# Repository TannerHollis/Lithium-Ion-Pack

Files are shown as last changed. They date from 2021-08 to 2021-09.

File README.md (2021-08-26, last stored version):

# Lithium Ion Pack
This project an open-source Lithium Ion Battery Pack charger and management system. Over the years, I have used many Lithium Ion cells and struggled over the exact workings of **smart-charging** and **cell balancing**. These terms are thrown around as to create a magic around the lithium ion battery charging process. The schematic, although very intricate can be broken down into **three** major components:
 **1.**  The battery charging circuit.
 **2.**  The battery balancing and protection circuit.
 **3.**  The voltage and current measurement circuit.

## The Battery Charging Circuit

I have used many battery charging Integrated Circuits in the past and have never been able to fully conceive what is going on behind the curtains of the larger devices which charge multiple cells. In fact, the basics *seem* very simple. Constant current until you achieve a specific voltage. Constant voltage until you stop after a certain time, giving the batteries a moment to "top-off". 

This battery pack is able to charge via a USB-C type port, which is a standard USB2.0 port used for Virtual Communications over USB. Since it's a standard USB2.0 connector inside of USB-C, only 5V is input to the device. The included Boost converter then steps-up the voltage through the [PAM2423](https://www.diodes.com/assets/Datasheets/PAM2421_22_23.pdf) DC-DC step-up voltage regulator. While this step-up regulator is capable of producing output voltages of up to 24V, the circuit is controlled by the feedback resistor network.

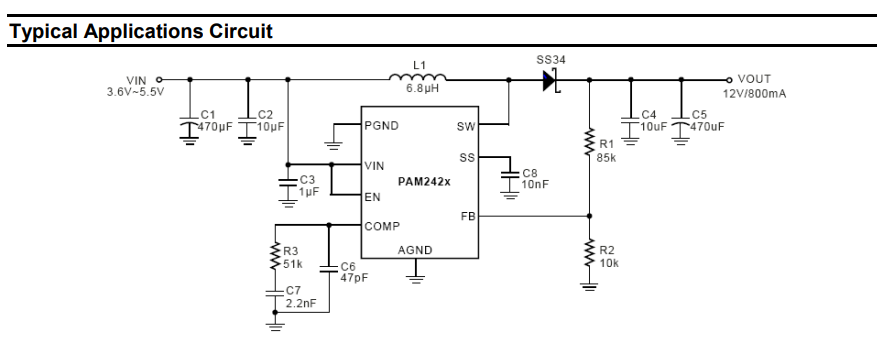
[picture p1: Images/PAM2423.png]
PAM2423 Typical Application Diagram


Since the resistor network can be controlled by a resistor network, I propose controlling the output voltage through the use of a digital potentiometer, [MCP4351](http://ww1.microchip.com/downloads/en/DeviceDoc/22242A.pdf). This device is essentially a digitally controlled resistor divider through SPI communications. 

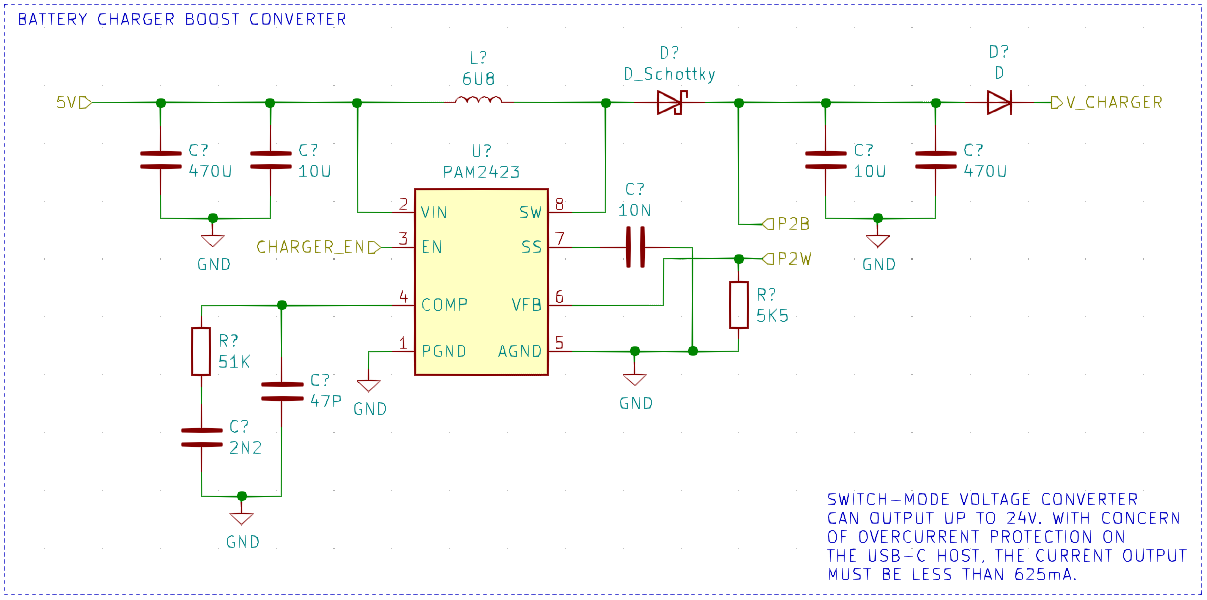
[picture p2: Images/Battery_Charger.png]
Battery Charger Circuit


When calculating the possible output voltages using only the resistor divider network, the following equation dictates the output voltage *(datasheet, pg. 6)*:

$$\begin{equation}V_{out} = (\frac{R_1}{R_2} + 1) * 1.262\end{equation}$$

The MCP4351 has a total different number of 257 different positions or "taps" that the potentiometer can place the "wiper". The resistor divider network's is calculated as follows *(datasheet, pg. 43)*:

$$\begin{equation}\begin{split}
R_{aw} &= \frac{100*10^3*n}{256}+75\\
R_{wb} &= \frac{100*10^3*(257-n)}{256}+75\\
\\
R_{aw}(0) &= 75\Omega\\
R_{wb}(0) &= 10.465k\Omega\\
\\
R_{aw}(257) &= 10.465k\Omega\\
R_{wb}(257) &= 75\Omega\\
\end{split}\end{equation}$$

Therefore, the the output voltage of the converter can be expressed as an quadratic with an asymptote, where $R_1 = R_{aw}$ and $R_2 = R_{wb}$:

$$\begin{equation}
\begin{split}
V_{out}(&n) = (100*10^3*\frac{n}{257 - n} + 1)*1.262V\\
V_{out}(&0) = 1.262V\\
V_{out}(&257) = \infin\\
\end{split}
\end{equation}
$$

Obviously, this equation poses a serious issue, infinity is not possible when the maximum allowed output voltage of the switching regulator is 24V. In order to combat this issue, only half of the wiper will be used. Since the wiper position at instruction *000h* for $R_{wb}$ is 0 Ohms, only the bottom half of the resistor divider in the MCP4351 and a static 5.5kOhm resistor will be used as follows:

$$\begin{equation}
\begin{split}
V_{out}(&n) = (\frac{100*10^3}{256}*\frac{n}{5.5*10^3} + 1)*1.262V\\
V_{out}(&0) = 1.262V\\
V_{out}(&257) = 24.30V\\
\end{split}
\end{equation}
$$

Creating the resistor divider this way with a fixed resistor on the bottom half of the feedback network creates a linear equation, which allows for more granularity. In fact, the minimum granularity between each LSb sent to the digital potentiometer is:

$$\begin{equation}V_{out}(1) - V_{out}(0) = 1.352V - 1.262V = 89.63mV\end{equation}$$

The resistor feeding the battery cells is 5 Ohms, which dictates current steps into the battery pack per change in voltage:

$$\begin{equation}I_{charge} = \frac{89.63V}{5\Omega} = 17.93 mA\end{equation}$$

This makes the current granularity small enough to manage on a larger scale and easier to manage from the current regulation PID controller. One thing to note in this setup is that due to the maximum wattage of the resistor of 5W, the device is only capable of sourcing up to 1 Amp into the battery pack. Which results in the following number of maximum voltage steps to the voltage regulator:
$$\begin{equation}n_{volts} = \frac{I_{chg}*R_{chg}}{89.63mV}=\frac{1A*5\Omega}{89.63mV}=55.8 \text{ steps truncated}=55\text{ steps}\end{equation}$$

## The Battery Balancing and Protection Circuit
While most IC's use a standard common drain N-Channel MOSFET pair to protect the battery pack, I am going with an easier approach to battery protection, with a P-Channel MOSFET. The gate is held high with a pull-up resistor until the device monitors an overcurrent/over-discharge condition. Otherwise the circuit features a soft-start turn-on with the help of a slow RC circuit with a fast discharge diode. Similar to that of a unstable 555 timer circuit.

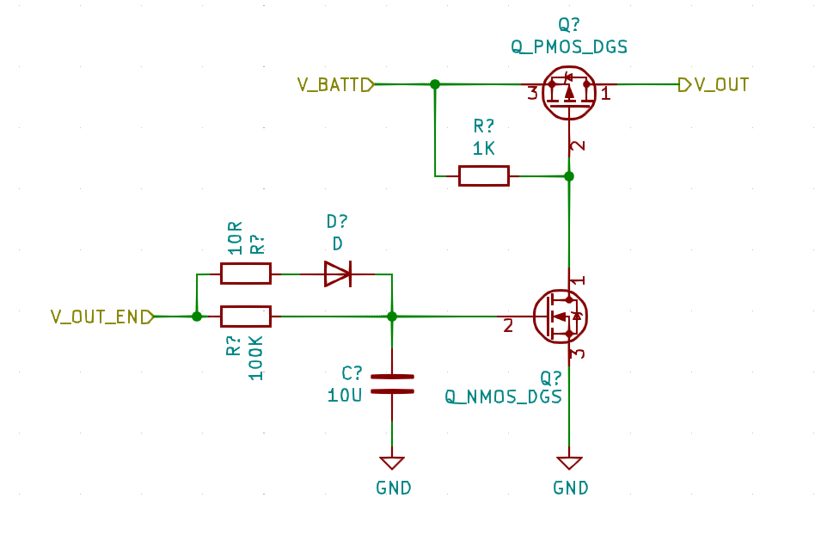
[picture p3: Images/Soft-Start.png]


When the signal to the N-Channel MOSFET is sent, it slowly charges the gate capacitor through the 100 kiloOhm capacitor. The RC time constant is 1 second. In the event of a fault - overcurrent, overdischarge or undervoltage - the capacitor quickly discharges through the 10 Ohm resistor through the diode. Once the forward voltage of diode is reached, the capacitor continues to discharge through the 100K resistor until completely discharged. This feature allows a rapid turn-off circuit and a slow turn-on circuit in the case of a close-onto-fault scenario.

TODO:

 - [ ] Continue editing this document
 - [ ] Assemble and build prototype
 - [ ] Revise design after basic testing
 - [ ] Verify programming and charging operation
 - [ ] Cycle battery discharge/charging

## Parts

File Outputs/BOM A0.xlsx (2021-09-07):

Bill of Materials
Lithium Ion Battery Pack |  |  |  | Started: September 3rd, 2021 Finished:
 |  |  |  | Total | 124 |  | $36.59045
Component | Reference(s) | Value | JLCPCB Code | Digikey Code | Quantity | Cost | Subtotal
Inductor | L2 | 6U8 |  | SRN5020TA-6R8MCT-ND | 1 | $0.57000 | $0.57000
Single-cell battery | BT1, BT2, BT3, BT4 | Battery_Cell |  |  | 4 |  | $0.00000
Unpolarized capacitor | C1, C2 | 30P |  | 490-1414-1-ND | 2 | $0.12000 | $0.24000
Unpolarized capacitor | C3, C9, C15, C16, C17, C18, C19, C20 | 100N |  | 490-4779-1-ND | 8 | $0.11000 | $0.88000
Unpolarized capacitor | C4, C11 | 470U |  | PCE4009CT-ND | 2 | $0.84000 | $1.68000
Unpolarized capacitor | C5 | 2N2 |  | 490-4931-1-ND | 1 | $0.10000 | $0.10000
Unpolarized capacitor | C6, C10 | 10U |  | 490-9965-1-ND | 2 | $0.34000 | $0.68000
Unpolarized capacitor | C7 | 47P |  | 490-1343-1-ND | 1 | $0.11000 | $0.11000
Unpolarized capacitor | C8 | 10N |  | 490-4781-1-ND | 1 | $0.10000 | $0.10000
Unpolarized capacitor | C12 | 33P |  | 490-1339-1-ND | 1 | $0.11000 | $0.11000
Unpolarized capacitor | C13, C14 | 22U |  | 490-5309-1-ND | 2 | $0.52000 | $1.04000
Unpolarized capacitor | C21 | 1U |  | 490-5860-1-ND | 1 | $0.33000 | $0.33000
Resistor | CSR1 | 5R |  | CB5JB5R00-ND | 1 | $0.50000 | $0.50000
Resistor | CSR2, CSR3, CSR4, CSR5 | 8L |  | 2019-TLRH3APTTE8L00FCT-ND | 4 | $1.58000 | $6.32000
Zener diode | D1 | 5V |  | 1727-8310-1-ND | 1 | $0.17000 | $0.17000
Schottky diode | D2, D3 | D_Schottky |  | 641-SS34B-HFCT-ND | 2 | $0.43000 | $0.86000
TVS Diode Array, 5.5V Standoff, 2 Channels, SOT-23 package | D4 | SP0502BAHT |  | F2714CT-ND | 1 | $0.71000 | $0.71000
Diode | D5 | D |  | SS16FL-TPMSCT-ND | 1 | $0.36000 | $0.36000
LED | D6, D7, D8 | LED |  | 732-5031-1-ND | 3 | $0.20000 | $0.60000
Ferrite bead | FB1 | Ferrite_Bead |  | MH3261-601YCT-ND | 1 | $0.10000 | $0.10000
USB-C Connector | J1 | USB4110-GF-A_REVB |  | 2073-USB4110-GF-A-1-ND | 1 | $1.41000 | $1.41000
Board Tabs | J2 | BATTERY_CONNECTIONS |  |  | 1 |  | $0.00000
Inductor | L1 | 6U8 |  | SRN5020TA-6R8MCT-ND | 1 | $0.57000 | $0.57000
N-MOSFET transistor, drain/gate/source | Q1, Q11 | 2N7002T-TP |  | 353-2N7002T-TPCT-ND | 2 | $0.40000 | $0.80000
P-MOSFET transistor, drain/gate/source | Q2, Q7, Q8, Q9, Q10 | MCH3375 |  | MCH3375-TL-WOSCT-ND | 5 | $0.36000 | $1.80000
P-MOSFET transistor, drain/gate/source | Q12 | IPB80P04P4L |  | 448-IPB80P04P4L06ATMA2CT-ND | 1 | $2.07000 | $2.07000
NPN transistor, base/collector/emitter | Q3, Q4, Q5, Q6 | MMST4401 |  | MMST4401TPMSCT-ND | 4 | $0.28000 | $1.12000
Resistor | R1, R41, R42, R43, R44, R56 | 1K5 |  | 541-4209-1-ND | 6 | $0.10000 | $0.60000
Resistor | R2, R5, R45, R46, R47, R48 | 100K |  | 541-4208-1-ND | 6 | $0.10000 | $0.60000
Resistor | R3 | 51K |  | 541-51KECT-ND | 1 | $0.10000 | $0.10000
Resistor | R4, R9, R14, R15, R16, R17, R18, R21 | 10K |  | 541-3983-1-ND | 8 | $0.10000 | $0.80000
Resistor | R6 | 5K49 |  | 541-5.49KFCT-ND | 1 | $0.10000 | $0.10000
Resistor | R7 | 25K5 |  | P25.5KFCT-ND | 1 | $0.10000 | $0.10000
Resistor | R8 | 115K |  | RMCF1206FT115KCT-ND | 1 | $0.10000 | $0.10000
Resistor | R10, R11, R25, R26, R27, R28, R29, R30, R31, R32, R55 | 1K |  | 541-3980-1-ND | 11 | $0.10000 | $1.10000
Resistor | R12 | 13K7 |  | 541-13.7KFCT-ND | 1 | $0.10000 | $0.10000
Resistor | R13 | 6K |  | RNCP1206FTD6K04CT-ND | 1 | $0.10000 | $0.10000
Resistor | R19, R20 | 3K3 |  | 541-4191-1-ND | 2 | $0.10000 | $0.20000
Resistor | R22, R24 | 5K1 20% |  | 541-5.10KFCT-ND | 2 | $0.10000 | $0.20000
Resistor | R23 | 1M |  | 541-4174-1-ND | 1 | $0.10000 | $0.10000
Resistor | R33, R34, R35, R36, R37, R38, R39, R40 | 732R |  | 541-732FCT-ND | 8 | $0.10000 | $0.80000
Resistor | R49, R50, R51, R52 | 160R |  | RMCF1206JT160RCT-ND | 4 | $0.10000 | $0.40000
Resistor | R53 | 10R |  | 541-4202-1-ND | 1 | $0.10000 | $0.10000
Resistor | R54 | 499K |  | RMCF1206FT499KCT-ND | 1 | $0.10000 | $0.10000
Resistor | R57, R58, R59 | 2K |  | RNCP1206FTD2K00CT-ND | 3 | $0.10000 | $0.30000
Tactile Switch | SW1 | KMR233GLFG |  | 401-1430-1-ND | 1 | $0.32045 | $0.32045
ARM Cortex-M3 MCU, 64KB flash, 32KB RAM, 32MHz, 1.65-3.6V, 37 GPIO, UFQFPN-48 | U1 | STM32L151C8UxA |  |  | 1 |  | $0.00000
Quad SPI Digital Potentiometer with Volatile Memory | U2 | MCP4351-104E |  | MCP4351-104E/ML-ND | 1 | $1.64000 | $1.64000
Step-Up Boost Controller | U3 | PAM2423 |  | PAM2423AECADJRDICT-ND | 1 | $1.12000 | $1.12000
3.5A, 18V, 500kHz ACOTTM SynchronousStep-Down Converter | U4 | RT7295A |  | 1028-1459-1-ND | 1 | $1.28000 | $1.28000
300mA low dropout linear regulator, low quiescent current very, low noise, shutdown pin, 3.3V fixed positive output, SOT-23-5/SOT-353-5/SC-70-5 | U5 | LDK130-33 |  | 497-13705-1-ND | 1 | $0.75000 | $0.75000
Low-Power, Quad-Operational Amplifiers, DIP-14/SOIC-14/SSOP-14 | U6, U7, U8 | LM2902 |  | 497-10426-1-ND | 3 | $0.64000 | $1.92000
Two pin crystal | Y1 | 8 MHz |  | 535-14365-1-ND | 1 | $0.43000 | $0.43000

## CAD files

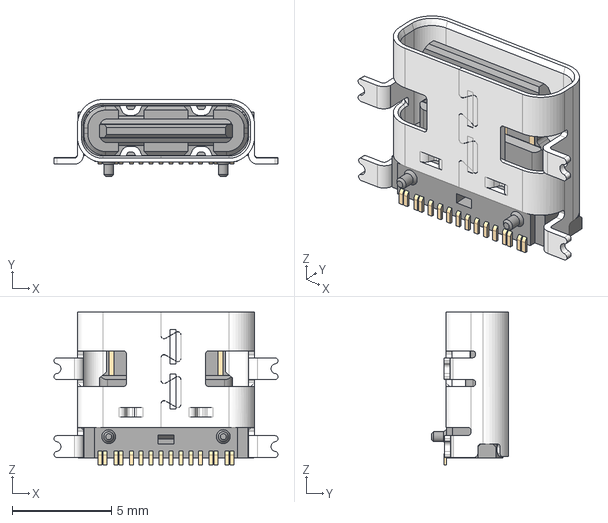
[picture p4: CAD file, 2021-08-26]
Parts/GCT_USB4110GFA/USB4110-GF-A.stp
11.3 x 3.89 x 7.70 mm

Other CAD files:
Parts/USB4110-GF-A_REVB/USB4110-GF-A_REVB.step

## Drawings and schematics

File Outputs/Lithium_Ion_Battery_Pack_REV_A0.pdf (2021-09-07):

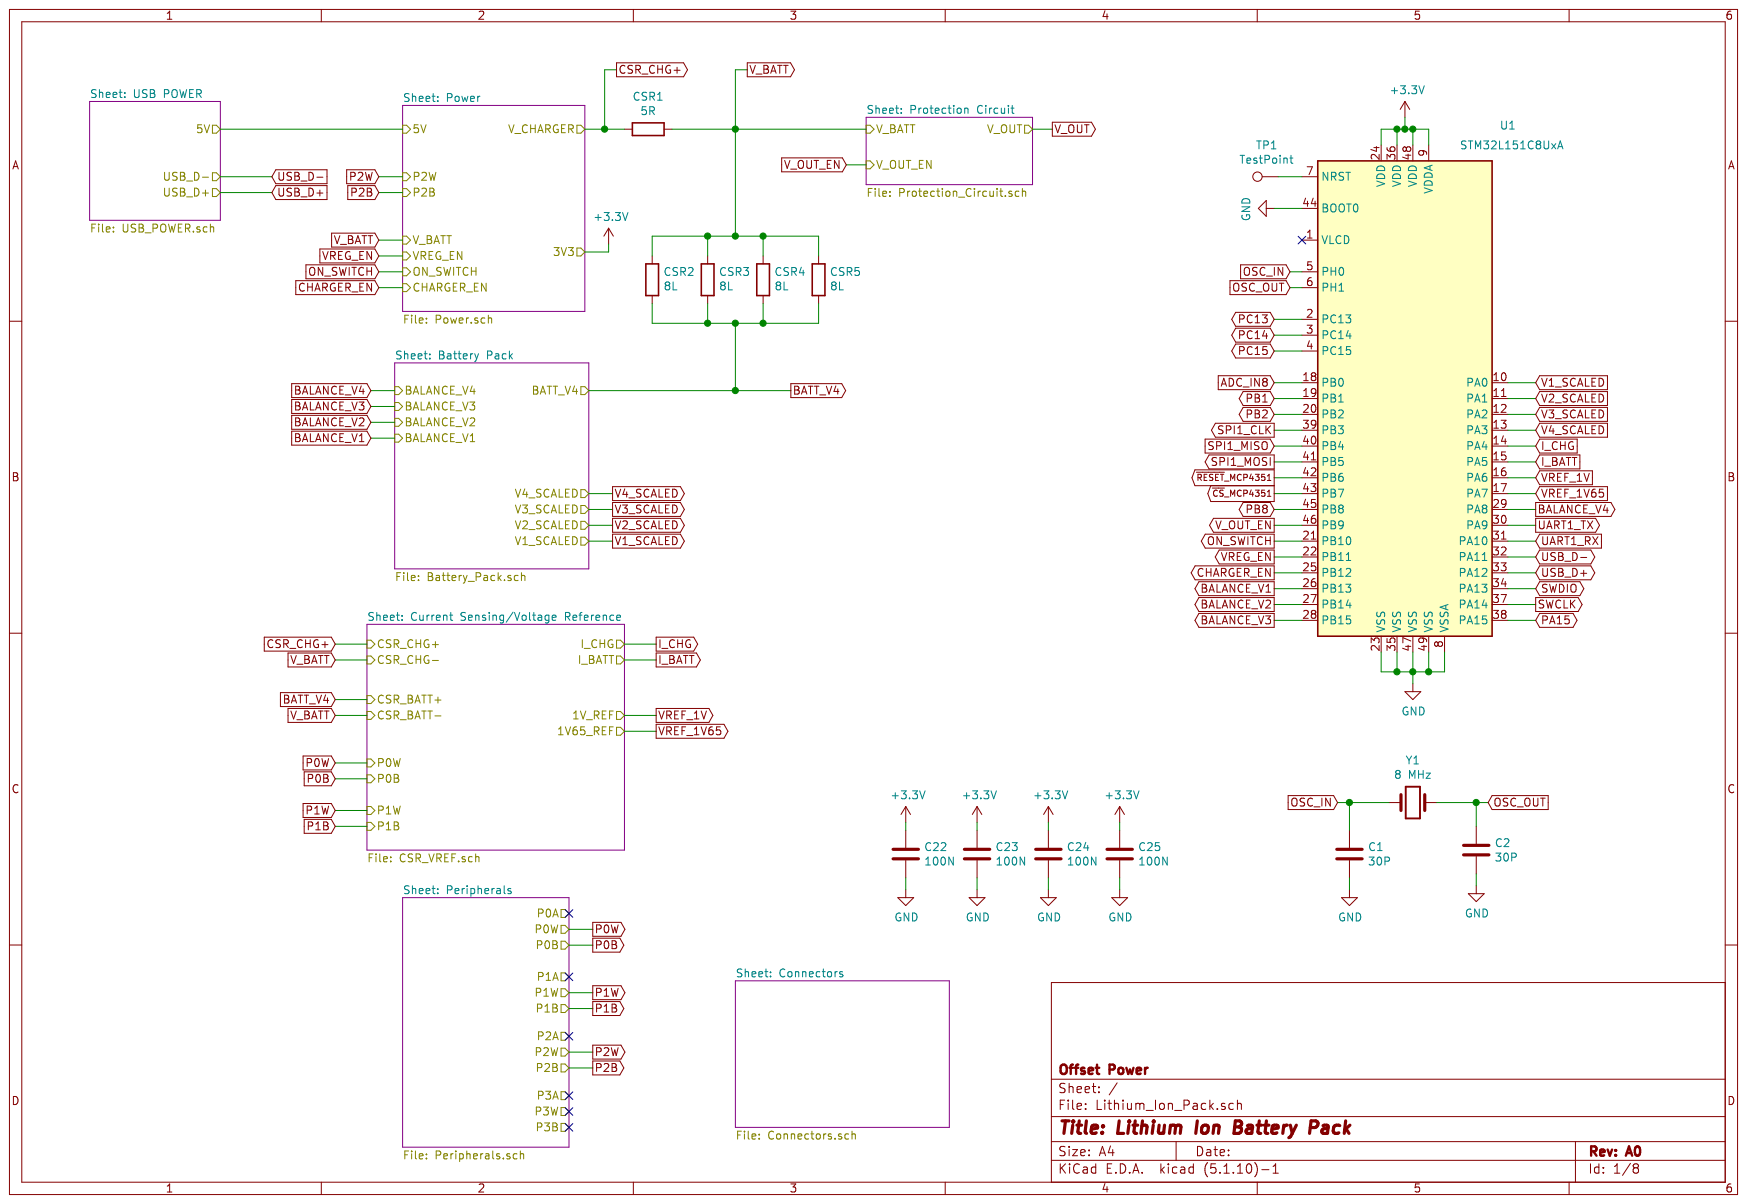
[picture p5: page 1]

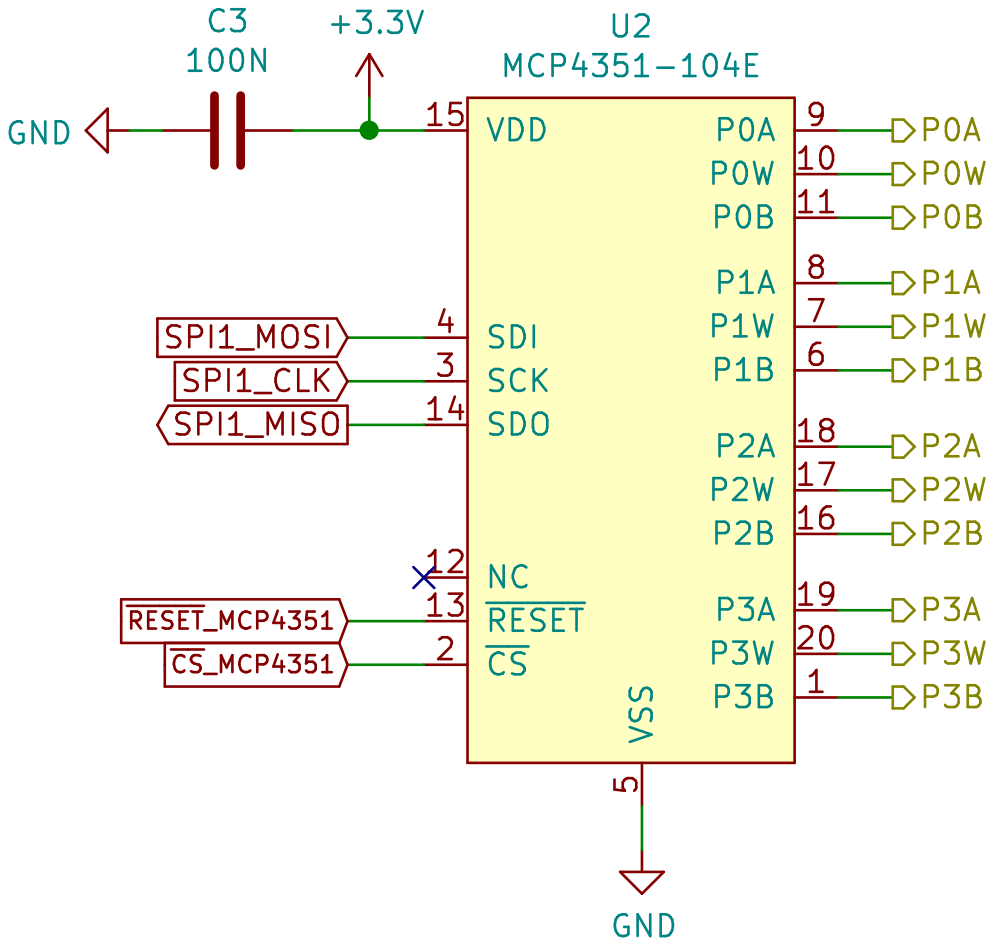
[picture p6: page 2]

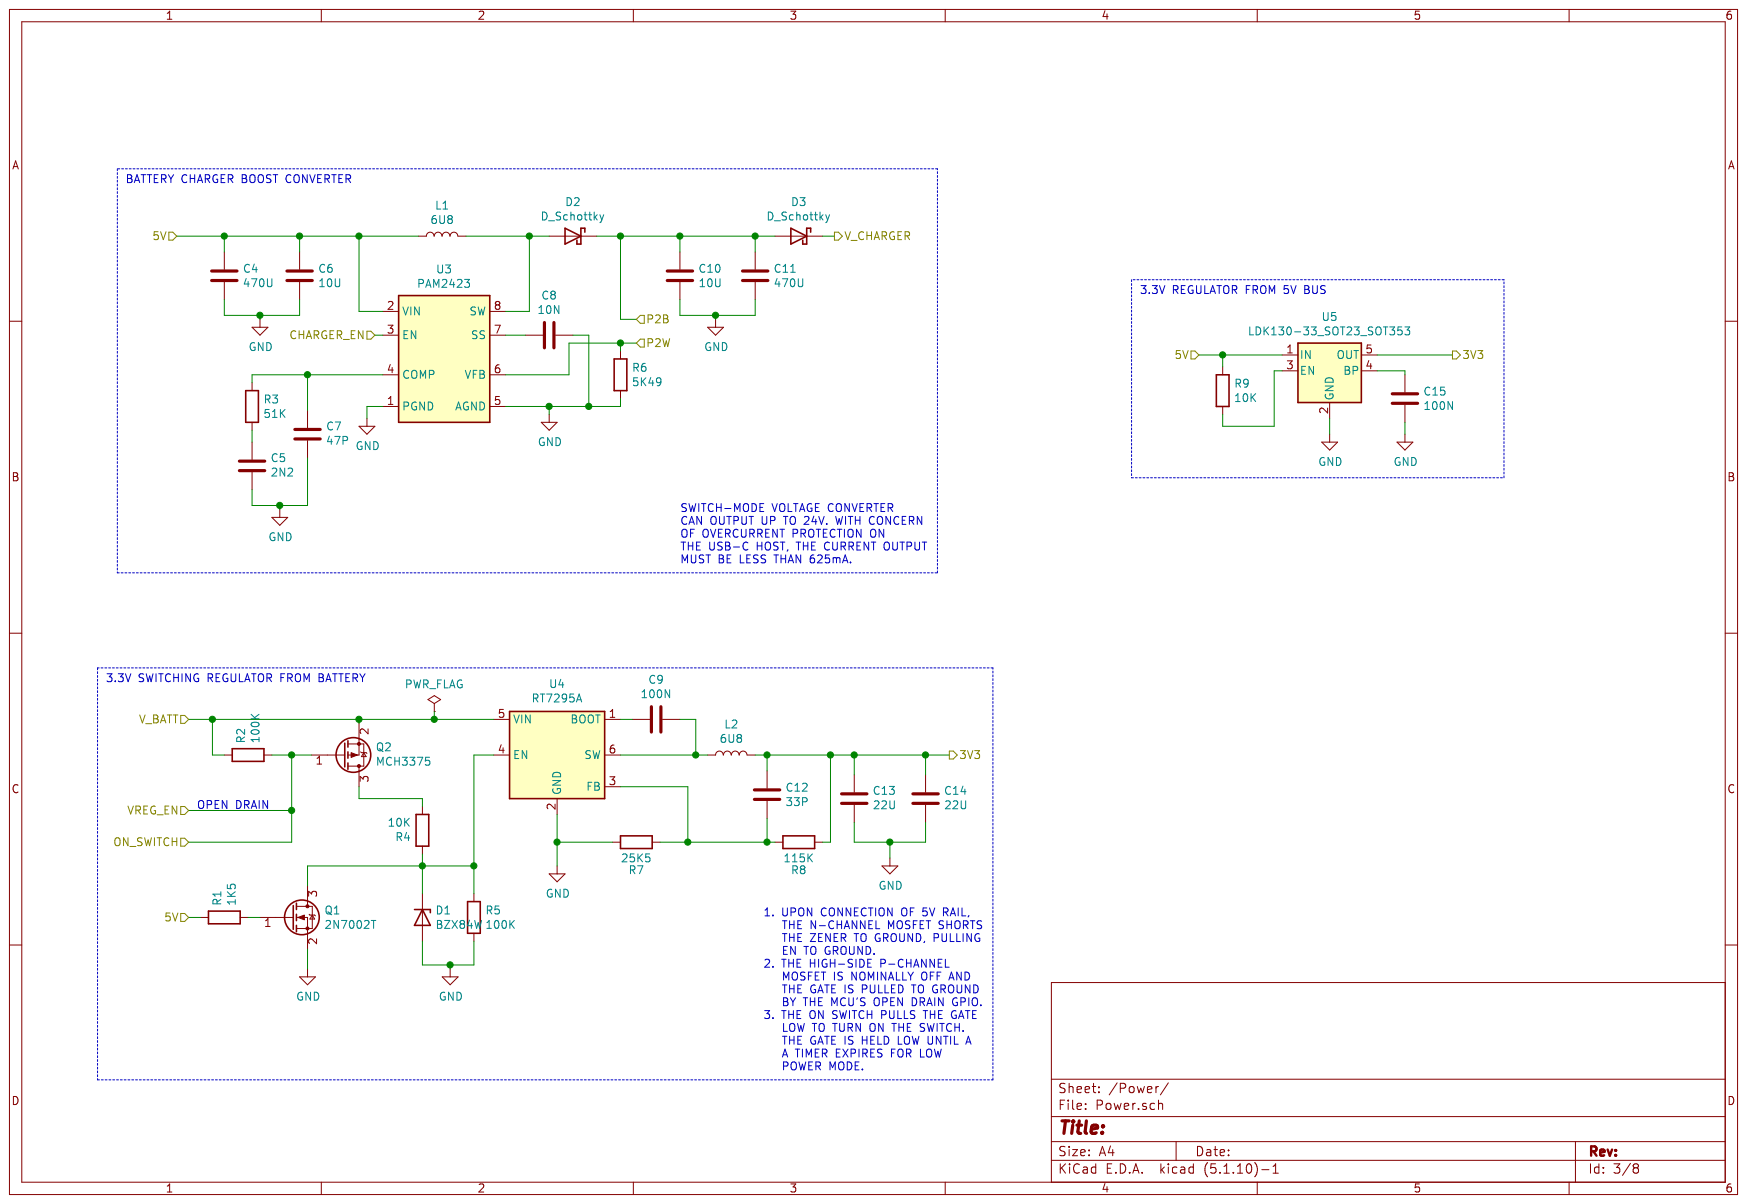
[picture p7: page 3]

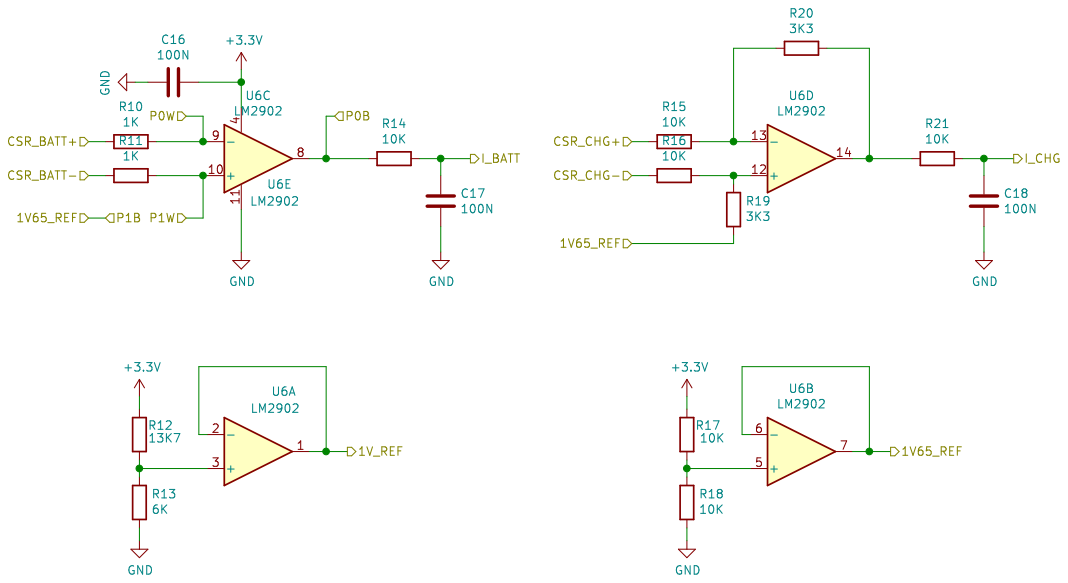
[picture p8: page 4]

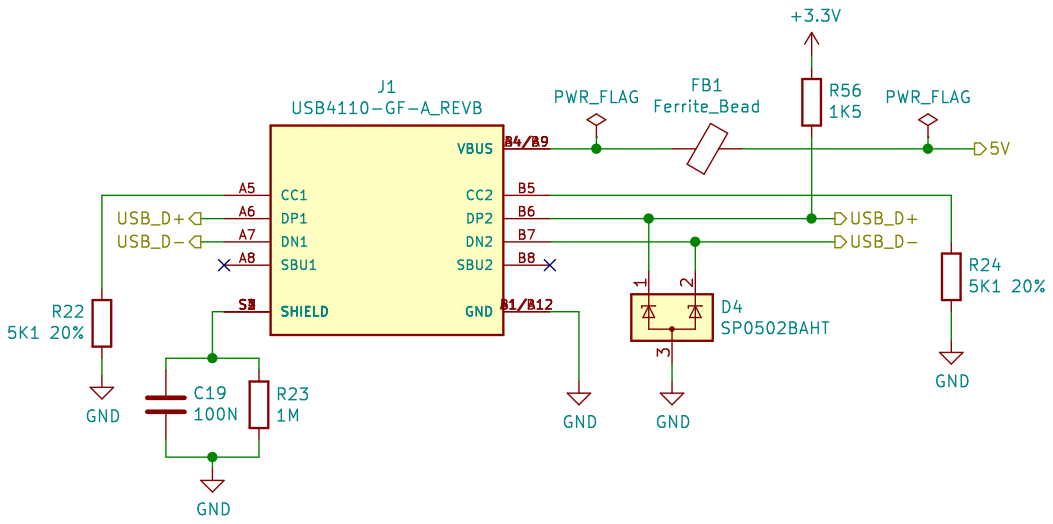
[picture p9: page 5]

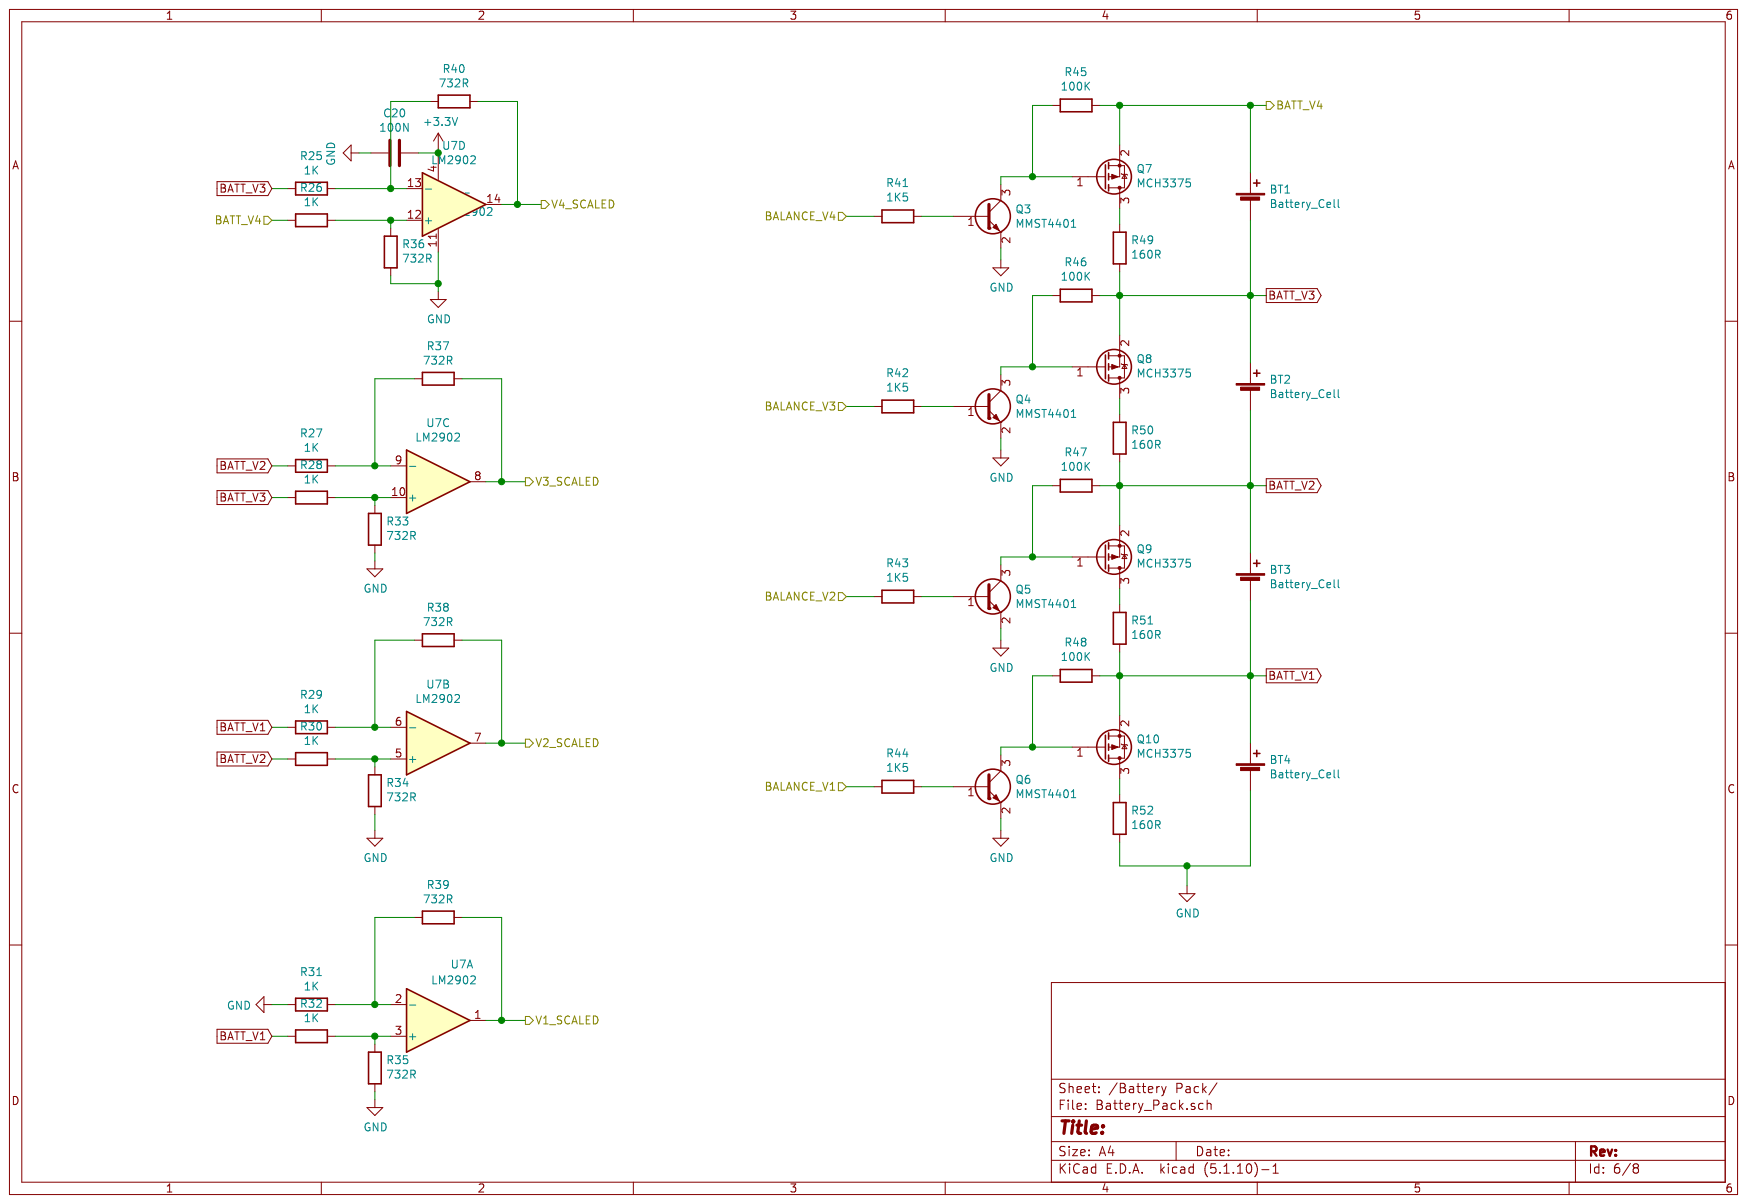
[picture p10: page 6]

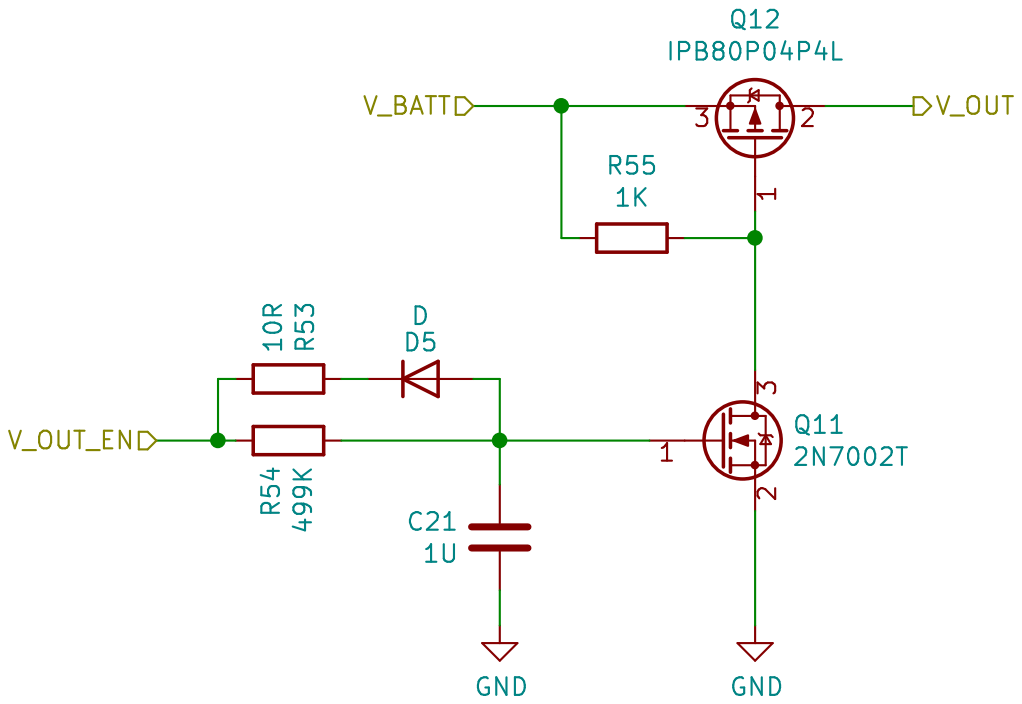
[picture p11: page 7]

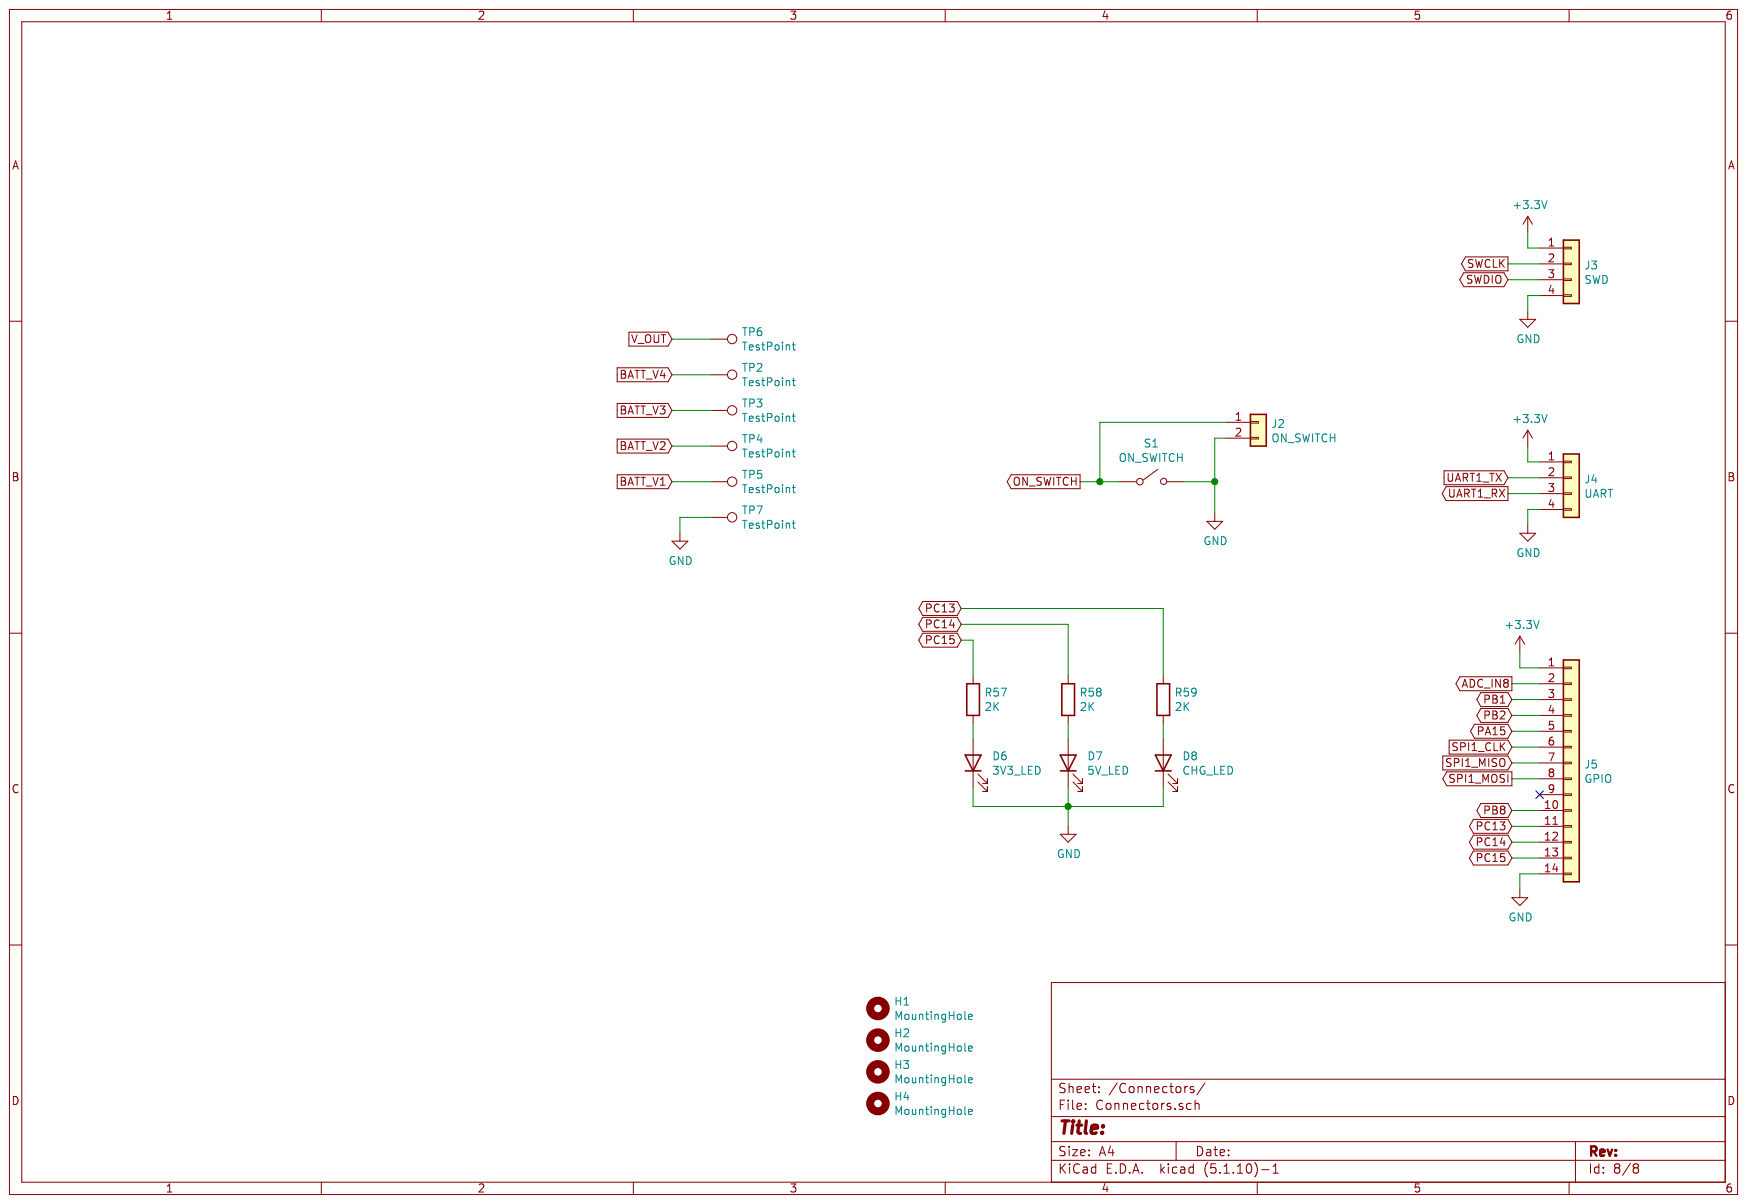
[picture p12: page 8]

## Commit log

2021-08-24 Initial commit
    Initial commit, 08/24/2021
    [Battery_Charger.sch, Battery_Pack.sch, CSR_VREF.sch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]
2021-08-26 KiCAD Schematic Finished
    Completed the KiCAD schematic, with MCU pinout complete.
    [Battery_Pack.sch, CSR_VREF.sch, Lithium_Ion_Pack.sch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]
2021-08-26 Re-Upload README
    Insert proper photo link
2021-08-26 Updated Charging Circuit
    Updated Charging Circuit for more granularity.
    [CSR_VREF.sch, Lithium_Ion_Pack.sch, Power.sch]
2021-08-26 Battery Charger/Current Sensor
    Updated Battery Charger Circuit and Charger Current Sensor Sensitivity to 5 Ohms
2021-08-26 Changes to Soft-Start
    Changed Soft-Start Mechanism to ramp up the voltage and quickly turn-off the PMOS in the event of a fault or short-circuit.
    [Battery_Pack.sch, CSR_VREF.sch, Lithium_Ion_Pack.sch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]
2021-09-07 Major Changes, Submit Rev A0
    Rev A0 sent to Board man. Final BOM. Added interfacing components. LED indicators.
    [BOM A0.xlsx, Battery_Pack.sch, CSR_VREF.sch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]

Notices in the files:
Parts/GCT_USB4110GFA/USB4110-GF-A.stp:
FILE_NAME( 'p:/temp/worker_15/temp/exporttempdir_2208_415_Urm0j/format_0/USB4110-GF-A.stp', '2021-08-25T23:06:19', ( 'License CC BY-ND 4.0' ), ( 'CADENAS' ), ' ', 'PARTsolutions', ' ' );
